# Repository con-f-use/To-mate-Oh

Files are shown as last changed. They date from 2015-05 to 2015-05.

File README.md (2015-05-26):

To-mate-Oh
==========

A [pomodoro](http://pomodorotechnique.com/) timer featuring a <a href="https://en.wikipedia.org/wiki/Capacitive_sensing">capacitve touch button</a>, <a href="https://en.wikipedia.org/wiki/Pulse-width_modulation">PWM</a>-driven LEDs and a <a href="https://en.wikipedia.org/wiki/Piezoelectricity#Actuators">piezo buzzer</a>. Based on the <a href="https://github.com/fakufaku/Pomodoro">Pomodoro project</a> by <a href="http://robinscheibler.org">Robin Scheibler</a> (github: <a href="https://github.com/fakufaku">FakuFaku</a>).

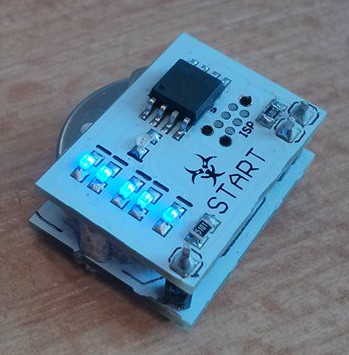
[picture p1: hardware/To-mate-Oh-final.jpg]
Home-cooked To-mate-Oh (not an actual tomato)


*Note: This readme might not always be up to date. Plese consult ./firmware/To-mate-Oh.h and the files in ./docu for more recent information.*

Introduction
------------

I saw the <a href="https://github.com/fakufaku/Pomodoro">POMODORO project</a> by <a href="http://robinscheibler.org">Robin Schreibler</a> and decided to build it. Some may know Robin by the name FakuFaku or from <a href="http://hackaday.com/2014/02/09/hack-all-the-things-in-the-time-you-save-with-this-led-pomodoro-timer/">Hackaday</a>. His' is a very nice layout with beautifully clean code.

__"That can't stand!"__, I thought, so first thing I did was soil the code and complicate the layout. And here is why: I was measuring the power consumption of the original Pomodoro. With a fresh coin cell at 3.3 V, the Pomodoro drained 1.6mA, even when in power down. Your average coin cell has about 200 mAh to give, ignoring the voltage decay. That means after 5 days at most, the battery is gone. This project has since then triggered Robin to fix this bug.

To-mate-Oh schematic. It has reverse polarity protection, four less resistors and replaced the button by a capacitive touch pad

I thought I can do better, and that kind of exploded in my face. Now the board is a quarter of Robin's footprint, has proper reverse polarity protection, drains only about 6 uA (when inactive) and uses less components. Most notably I could do away with four resistors and the switch. The design uses capacitive sensing now and drives the LEDs directly with PWM. The PWM has the added benefit of dimming the LEDs to indicate passed time. You can tweak the duty cycle in code to work with the old hardware (or bridge the unnecessary resistors). On the down side, the code is much, much uglier (but uses only a third of the space on the micro controller). I think it's an improvement, but judge for yourself.

Anyways, many thanks to Robin for making his project open source and being awesome!

Using the Board
---------------

From Robins original documentation (with additions of my own):

1. One click starts a 25 minutes _work_ counter. Five LEDs indicate how many slices of five minutes are left. Every minute the leading led flashes number of times equal to the passed minutes in that slice. It also dims in brightness to indicate the minutes passed. There is a discrete beep when the 25 minute timer expires. The LED then flashes to remind you to go into _rest_ mode.
2. A second click starts a 5 minutes _rest_ counter. The status LED is turned on. There is a discrete beep when it expires. Then the timer turns off.
3. If you wish to turn the timer off during _rest_ mode, click the button a third time.

When you insert a fresh battery, a calibration for the cap sense button is performed. To not touch the upper side of the board during that period. After a successful calibration the To-mate-Oh will circle through its LEDs and beep. If you count the beeps or how often a different LED is lit, it will give you the calibration constant. If the calibration fails, the To-mate-Oh will blink LED2 for five seconds. If this occurs, most likely the sense pad was accidentally connected to a large capacity (e.g. you) or ground.

Making/Ordering the Board
-------------------------

You can order the circuit board at a board house of your choice. e.g. <a href="http://dirtypcbs.com/view.php?share=3243&accesskey=5920ddd4c2010ad6628f47974e820113">Dirty PCBs</a> ($14 to get 20 To-mate-Oh boards). The total price per To-mate-Oh (board + components) should come in at around $3-4. The board is still one sided, but you have to solder the components, break it in two, and sandwich-connect the two halves by soldering them together with solid leads of metal (pin headers work fine). If you live in Germany or Austria, I might be willing to sell you a kit with the board and all components required. Just <a href="mailto:con-f-use@gmx.net?Subject=To-mate-Oh%20Order">contact me</a>.

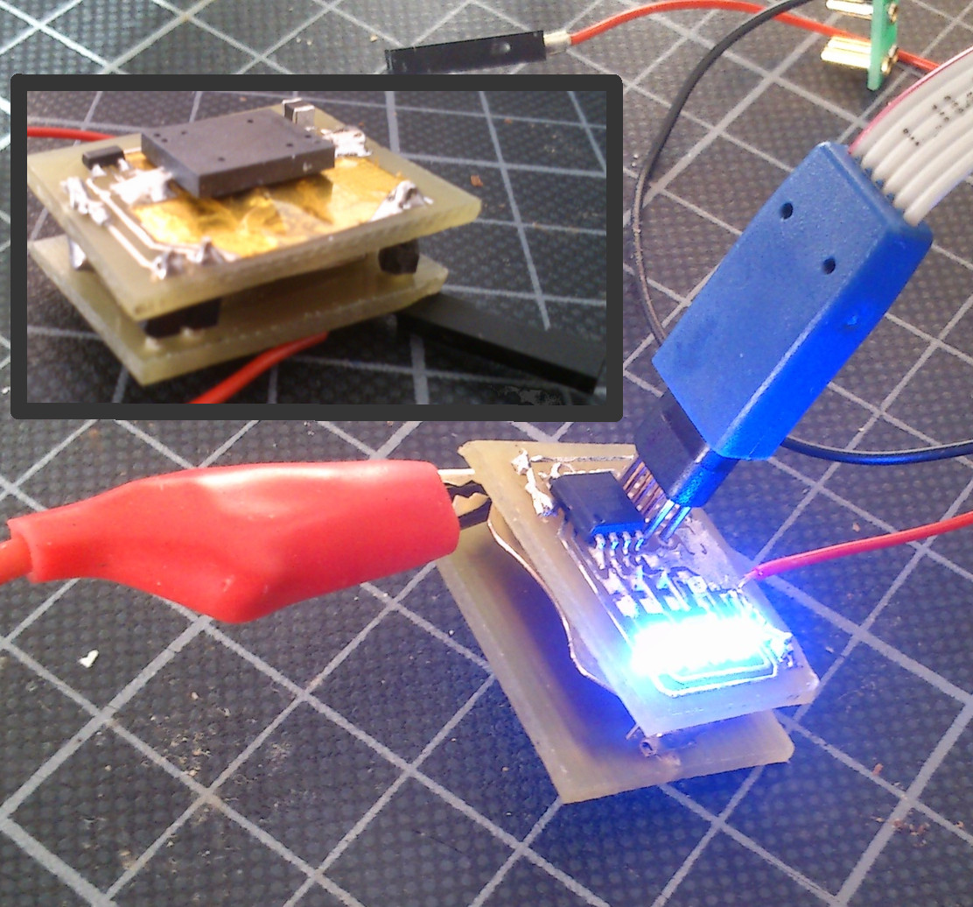
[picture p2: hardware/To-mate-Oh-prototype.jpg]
First prototype being programmed


If you choose to make the board yourself, there are tons of good introductions on <a href="http://hackaday.com/2008/07/28/how-to-etch-a-single-sided-pcb/">how to etch circuit boards</a> at home and <a href="http://store.curiousinventor.com/guides/How_To_Solder"> how to solder</a> (sorry this is pay-for-view now which is very unnerving, try the <a href="https://www.youtube.com/watch?v=b9FC9fAlfQE">EEVBlog tutorial</a>) components to them. With that in mind, the eagle files, pictures and schematics in the ./hardware directory should be all the instructions you need. The coin cell holder is sandwiched between the two halves of the board. You might need to fill the middle trough hole pad under the buzzer with something to make proper contact with the negative contact of the battery on the other side of the board. I listed the components and tools needed below. The components are available e.g. on <a href="https://www.mouser.com/ProjectManager/ProjectDetail.aspx?AccessID=97d69422c2">Mouser</a>. Values and part numbers are only recommendations, use whatever you have. I listed what I used in brackets:

 - Atmel AtTiny25/45/85 microcontroller
 - 5x LED all one color, SMD 0805 (VLMB1300-GS08)*
 - 1x LED any other color, SMD 0805 (VLMS1300-GS08)*
 - 2x 3.3 k Ohm Resistor, SMD 0805[^1]
 - 1x NPN BJT transistor, SOT-23 (BC857)[^2]
 - 1x 220uH Inductor, SMD 1007
 - 1x Buzzer, SMD (Kobitone 254-PB119-ROX)
 - 1x CR2032 coin cell and holder
 - A bit of solid core wire, pin headers or component leads
 - Optional:
    - 1x MOSFET P-Channel, SOT-23 (SI2371ESD)[^3]
    - 1x 1-10 uF Capacitor, SMD 1210[^4]

__Warning: *If you use LEDs other than the Vishay 1300 series, you might get differences in brightness or in very rare cases damage the ATTiny. The LEDs are PWM-dimmed with no current limiting resistor. Not all LEDs have the same efficiency and forward voltage. Current through them may vary. And even at same current, the brightness may vary. The ATTiny must only supply up to 40mA max per output pin and only sink 10mA per input. Additionally all inputs together must not sink more than 60mA (150 mA source per output). A regular CR2032 can provide as muchs as 300mA of current. At the low duty cycles in the program and 3.3V supply voltage from the battery there should be no problem no matter the LEDs. But if you use non-standard LEDs or supply the circuit with more than 3.3V, e.g. when programming, give it a thought or two and consult the <a href="http://www.atmel.com/images/atmel-2586-avr-8-bit-microcontroller-attiny25-attiny45-attiny85_datasheet.pdf">ATTiny's datasheet</a>.__

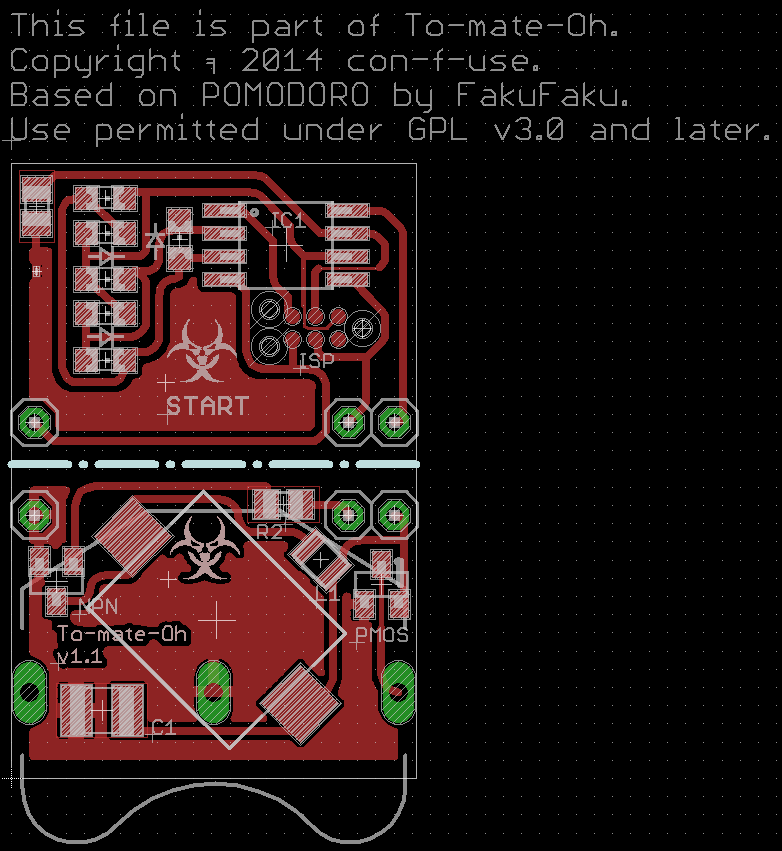
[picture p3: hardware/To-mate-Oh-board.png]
To-mate-Oh Board


Tools for soldering:

- Good soldering ion with small tip for SMD soldering
- Third hand tool
- Wire cutter
- Programmer for the micro controller (e.g. <a href="http://www.geppettoelectronics.com/2014/08/usb-isp-user-guide.html">USB μISP</a>)
- <a href="http://www.tag-connect.com/">Tag connect adapter</a> [^5]

If you are making the board yourself (so you really don't want to order it?):

- Laser printer
- Dremel or similar tool for drilling small holes
- Tool to cut your copper clad board (for thin material -> scissors)
- Cloth iron or laminator (or UV photo resist, developer, transparencies and UV exposure unit)
- Etchant resistant container
- Tab water
- Workspace and clothing that don't mind dirt and discoloration
- __Etchant resistant Gloves__
- __Safety glasses__

__Warning: Etching circuit boards involves corrosive chemicals with the usual dangers (eye damage, chemical burns, damage to the respiratory system, damage to the environment and surroundings, etc.). Know what you're are doing!__

Compiling and flashing the firmware
-----------------------------------

```bash
# Under Ubuntu running these in the ./firmware directory should do:
sudo apt-get install
sudo apt-get install gcc-avr avrdude avr-libc
make flashfuse
```

To flash the firmware to the micro controller run "make flashfuse" after you connected the ISP header on the board to your programmer. The board does not connect the Tag Connect's positive voltage pin to the micro controller. The power pin of your programmer will have to be connected manually to the battery holder's positive contact. This is to avoid exposing an inserted battery to the USB voltage, so **before programming, take the battery out and connect positive voltage yourself.**

The firmware for this project requires avr-gcc and avr-libc (a C-library for the AVR micro controllers). Please read the instructions on how to <a href="http://www.nongnu.org/avr-libc/user-manual/install_tools.html">install the GNU toolchain for avr</a> (avr-gcc, assembler, avr-libc, linker, make, etc.) if above command's did not work for you. Additionally, <a href="http://www.ladyada.net/learn/avr/index.html">Lady Ada's avr tutorial</a> covers the basics of flashing firmware to a micro controller nicely. Running "make flashfuse" in the ./firmware direcotry should be sufficient. You will have to edit the "DEVICE" variable in the Makefile to reflect of the ATTiny25/45/85s you are using. If you are using a programmer other than a <a href="http://www.ladyada.net/make/usbtinyisp/">USBtinyISP</a> variant (btw.: you can build USBtinyISP at home) you need to edit that into the Makefile as well.

If you change the firmware or fuse bits, be aware that the cap sensing and led timing is very sensitive. In the ./firmware/To-mate-Oh.h are a few settings related to LED PWM and timeouts (scroll way down in the .h file until after this documentation).

*Note: There is much room for optimization. For instance, one could get rid of the delays by using a timer for the short led pulses and putting the controller to sleep for the long ones (the watchdog timer can go down to 15 ms). The watchdog timer is not that accurate and temperature stable though. Speaking of accuracy, the delay lengths could be adjusted for more accurate timing.*

Copyright
---------

This file is part of the To-mate-Oh project. Copyright © 2014 con-f-use. Use permitted under GNU General Public License (see LICENSE.txt).

To-mate-Oh is based on the Pomodoro timer by Robin Scheibler (FakuFaku). See <http://robinscheibler.org> and <https://github.com/fakufaku/Pomodoro> for more details on the original project.

To-mate-Oh is a free electronics project: you can redistribute it and/or  modify it under the terms of the GNU General Public License as published by the Free Software Foundation, either version 3 of the License, or (at your option) any later version.

To-mate-Oh is distributed in the hope that it will be useful, but WITHOUT ANY WARRANTY; without even the implied warranty of MERCHANTABILITY or FITNESS FOR A PARTICULAR PURPOSE. See the GNU General Public License for more details.

You should have received a copy of the GNU General Public License along with To-mate-Oh. If not, see <http://www.gnu.org/licenses/>.

The following files comprise To-mate-Oh: ./docu/docu.pdf, ./docu/doxygen.cfg, ./docu/doxygen.sh, ./firmware/Makefile, ./firmware/To-mate-Oh.c, ./firmware/To-mate-Oh.h, ./hardware/To-mate-Oh.brd, ./hardware/To-mate-Oh.sch, ./hardware/To-mate-Oh-board.png, ./hardware/To-mate-Oh-etch.pdf, ./hardware/To-mate-Oh-schematic.pdf, ./hardware/To-mate-Oh-prototype.jpg, ./hardware/To-mate-Oh-final.jpg, ./hardware/To-mate-Oh-kit.jpg, ./hardware/To-mate-Oh-panel.gerber.zip, ./LICENSE.txt, ./README.md

Their use is permitted under the terms of GNU General Public License as well. If you want to use any part under different terms, please feel free to ask the author for his permission.

[^1]: The 3k3 resistor on the base of the NPN shouldn't be lower or it might interfere with programming.
[^2]: The NPN can be pretty generic but should be able to stomach the spikes created by the inductor.
[^3]: The P-MOS should have a threshold voltage well below the battery voltage to work as reverse polarity protection. A low on resistance is nice, too. If you don't use it, short source and drain together. The SI2371ESD is nice because it includes TVS diodes for ESD protection.
[^4]: The 10uF cap is a good thing to enhance battery life by smoothing out peak drains/spikes. It is however not necessary.
[^5]: The tag connect adapter is only needed if you don't want to solder temporary wires for programming. It has a much smaller footprint and some other advantages. Some people have build clones.You could also program the chip off board.

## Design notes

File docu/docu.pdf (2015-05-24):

## To-mate-Oh

1.1

Generated by Doxygen 1.8.6

Mon Jan 12 2015 13:12:34

CONTENTS | 1

## Contents

## 1 To-mate-Oh - A small Pomodoro timer with a capacitive button


Figure 1: Home made To-mate-Oh (not an actual tomato)

Copyright

This file is part of the To-mate-Oh project. Copyright © 2014 con-f-use. Use permitted under GNU General Public License (see LICENSE.txt).
To-mate-Oh is based on the Pomodoro timer by Robin Scheibler (FakuFaku). See http://robinscheibler.-org (http://robinscheibler.org) and https://github.com/fakufaku/Pomodoro for more details on the original project. To-mate-Oh is a free electronics project: you can redistribute it and/or modify it under the terms of the GNU General Public License as published by the Free Software Foundation, either version 3 of the License, or (at
your option) any later version.
To-mate-Oh is distributed in the hope that it will be useful, but WITHOUT ANY WARRANTY; without even the implied warranty of MERCHANTABILITY or FITNESS FOR A PARTICULAR PURPOSE. See the GNU General Public License for more details.
You should have received a copy of the GNU General Public License along with To-mate-Oh. If not, see http://www.gnu.org/licenses/

The following files comprise To-mate-Oh: ./docu/docu.pdf, ./docu/doxygen.cfg, ./docu/doxygen.sh, ./firmware/-
Makefile, | ./firmware/To-mate-Oh.c, | ./firmware/To-mate-Oh.h, | ./hardware/To-mate-Oh.brd, | ./hardware/To-
mate-Oh.sch, | ./hardware/To-mate-Oh-board.png, | ./hardware/To-mate-Oh-etch.pdf, | ./hardware/To-mate-Oh-
schematic.pdf, ./hardware/To-mate-Oh-prototype.jpg, ./hardware/To-mate-Oh-final.jpg, ./hardware/To-mate-Ohkit.jpg, ./LICENSE.txt, ./README,txt

Their use is permitted under the terms of GNU General Public License as well. If you want to use any part under different terms, please feel free to ask the author for his permission.

### 1.1 Introduction

I saw the POMODORO project (https://github.com/fakufaku/Pomodoro) by Robin Schreibler (http://robinscheibler.org) and decided to build it. Some may know Robin by the name FakuFaky. His’ is a very nice layout with beautifully clean code.

Generated on Mon Jan 12 2015 13:12:34 for To-mate-Oh by Doxygen

### 2 CONTENTS

That can’t stand, I thought, so first thing I did was soil the code and complicate the layout. And here is why: I was measuring the power consumption of the original POMODORO. With a fresh coin cell at 3.3 V, the POMODORO drained 1.6mA, even when in power down. Your average coin cell has about 200 mAh to give, ignoring the voltage decay. That means after 5 days at most, the battery is gone.

11/5/14 9:57 PM /home/confus/eagle/To-mate-Oh/hardware/To-mate-Oh.sch (Sheet: 1/1)

VCC

8 | PB1(MISO) | 6 PB5(NRES) | 1 GND
4 | PB0(MOSI) | 5 PB2(SCK/ADC1) | 7 PB3(ADC3) | 2 PB4(ADC2) | 3

MISO

1 | +V
2 | | SCK
3 | MOSI 4 | RST
5 | | GND
6
1 | 1
1 | 1
1 | 1

TCH

P$1

A

B

C

D

1 | 2 | 3 | 4

A

B

C

D

1 | 2 | 3 | 4

Figure 2: New To-mate-Oh schematic. It has reverse polarity protection, four less resistors and replaced the button by a capacitive touch pad.

I thought I can do better, and that kind of exploded in my face. Now the board is a quarter of Robin’s footprint, has proper reverse polarity protection, drains only 7 uA when inactive and uses less components. Most notably I could do away with four resistors and the switch. The design uses capacitive sensing now. The code still works with the old hardware though. On the down side, the code is much uglier (but uses only a third of the space on the micro controller). I think it’s an improvement, but judge for yourself.

Anyways, many thanks to Robin for making his project open source and being awesome!

### 1.2 Making the Board

You can order the circuit board at a board house of your choice. e.g. Dirty PCBs. (http://dirtypcbs.com/view.php?share=3243&accesskey=5920ddd4c2010ad6628f47974e820113) The board is still one sided, but you have to solder the components, break it in two, and sandwich-connect the two halves by soldering them together with solid leads of metal (pin headers work fine).

1.2 Making the Board | 3


Figure 3: First prototype being programmed

If you choose to make the board yourself, there are tons of good introductions on how to etch circuit boards (http://hackaday.com/2008/07/28/how-to-etch-a-single-sided-pcb/) at home and how to solder (http://store.curiousinventor.com/guides/How_To_Solder) components to them. With that in mind, the eagle files, pictures and schematics in the ./hardware directory should be all you need, except for the components of course. I listed the components and tools needed below. The components are available e.g. on Mouser. (https://mouser.com) Exact values and part numbers are only recommendations. I listed what I used in brackets:

- Atmel AtTiny25/45/85 microcontroller
- 5x LED all one color, SMD 0805 (VLMB1300-GS08)∗
- 1x LED any other color, SMD 0805 (VLMS1300-GS08)∗
- 2x 3.3 k Ohm Resistor, SMD 0805 1
- 1x NPN BJT transistor, SOT-23 (BC857) 2
- 1x 220uH Inductor, SMD 1007
- 1x Buzzer, SMD (Kobitone 254-PB119-ROX)
- 1x CR2032 coin cell and holder
- Optional:
1x MOSFET P-Channel, SOT-23 (SI2371) 3 ,
1x 10 uF Capacitor, SMD 1210 4

Warning

If you use LEDs other than the Vishay 1300 series, you might get differences in brightness and even damage your micro controller. The LEDs are PWM-dimmed with no current limiting resistor. Not all LEDs have the same efficiency and forward voltage, meaning current through them may vary. And even at same current, the brightness may vary. The ATTiny must only supply up to 40mA max per output pin and only sink 10mA per input. Additionally all inputs together must not sink more than

1The 3k3 resistor on the base of the NPN shouldn’t be lower or it might interfere with programming.
2The NPN can be pretty generic but should be able to stomach the spikes created by the inductor.
3The P-MOS should have a threshold voltage well below the battery voltage to work as reverse polarity protection. A low on resistance is nice, too. If you don’t use it, short source and drain together.
4The 10uF cap is a good thing to enhance battery life by smoothing out peak drains/spikes. It is however not necessary.

### 4 CONTENTS

60mA (150 mA source per output). At the low duty cycles in the program and 3.3V supply voltage from the battery there should be no problem no matter the LEDs. But if you use non-standard LEDs or supply the circuit with more than 3.3V, e.g. when programming, give it a thought or two and consult the ATTiny’s datasheet (http://www.atmel.com/images/atmel-2586-avr-8-bit-microcontroller-attiny25-attiny45-attiny85_datasheet.pdf) .

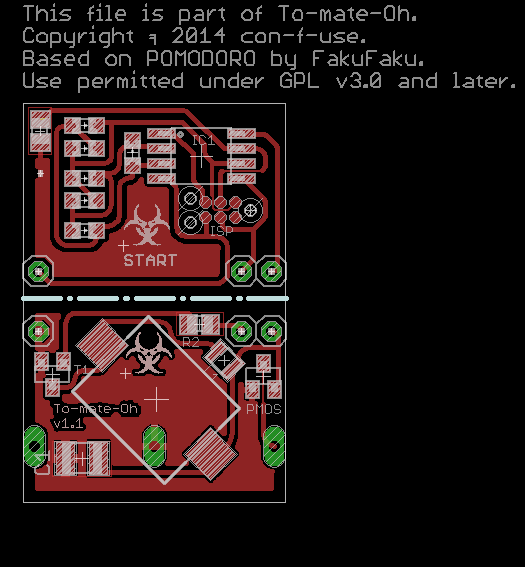
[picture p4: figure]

Figure 4: To-mate-Oh Board

Tools for soldering:

- Good soldering ion with small tip for SMD soldering
- Third hand tool
- Clothing ion
- Programmer for the micro controller
- Tag connect adapter (http://www.tag-connect.com/) 5

If you are making the board yourself (if you really don’t want to order it):

- Laser printer
- Dremel or similar tool for drilling small holes
- Tool to cut your copper clad board (for thin material -> scissors)
- Cloth iron or laminator
- Acid resistant Gloves
- Acid resistant container to hold your etching solution
- Safety glasses

Warning

Etching circuit boards involves corrosive chemicals with the usual dangers (eye damage, chemical burns, damage to the respiratory system, etc.).

5The tag connect adapter is only needed if you don’t want to solder temporary wires for programming. It has a much smaller footprint and some other advantages. Some people have build clones.You could also program the chip off board.

1.3 Compiling and flashing the firmware | 5

### 1.3 Compiling and flashing the firmware

The firmware for this project requires avr-gcc and avr-libc (a C-library for the AVR controller). Please read the instructions at http://www.nongnu.org/avr-libc/user-manual/install_tools.html for how to install the GNU toolchain (avr-gcc, assembler, linker etc.) and avr-libc.

Lady Ada’s avr tutorial (http://www.ladyada.net/learn/avr/index.html) covers the basics of flashing firmware to a microcontroller nicely.

However, running "make program" in the firmware direcotry should be sufficient. Maybe you will have to edit the Makefile especially if you are using a programmer other than USBtinyISP (http://www.ladyada.net/make/usbtinyisp/) (btw.: you can build USBtinyISP at home).

To flash the firmware to the microcontroller run "make flashfuse" after you connected the ISP header on the board to your programmer. The board does not connect the Tag Connect’s plus pin to the micro controller. The power pin of your programmer will have to be connected manually to the battery holder’s positive contact. This is to avoid exposing an inserted battery to the USB voltage, so before programming, take the battery out.

If you change the firmware or fuse bits, be aware that the cap sensing and led timing is very sensitive. In the ./firmware/To-mate-Oh.h are a few settings related to LED PWM and timeouts (scroll way down in the .h file until after this documentation).

Note

There is much room for optimization. For instance, one could get rid of the delays by using a timer for the short led pulses and putting the controller to sleep for the long ones (the watchdog timer can go down to 15 ms). The watchdog timer is not that accurate and temperature stable though. Speaking of accuracy, the delay lengths could be adjusted for more accurate timing.

### 1.4 Using the Board

From Robins original documentation:

1. One click starts a 25 minutes work counter. Five yellow LED indicates how many slices of five minutes are left. There is a discrete beep when the timer expires. The LED then flashes to remind you to go into rest mode.
2. A second click starts a 5 minutes rest counter. A red LED is turned on. There is a discrete beep when it expires. Then the timer turns off.
3. If you wish to turn the timer off during rest mode, click the button a third time.

When you insert a fresh battery, a calibration for the cap sense button is performed. After a successful calibration the To-mate-Oh will circle through its LEDs and beep. If you count the beeps or how often a different LED is lit, it will give you the calibration constant. If the calibration fails, the To-mate-Oh will blink LED2 for five seconds. Most likely the sense pad is connected to a large capacity or ground then.

## 2 File Index

### 2.1 File List

Here is a list of all files with brief descriptions:

/home/confus/misc/prog/eagle/To-mate-Oh/firmware/To-mate-Oh.c
Contains the firmware to flash the microcontroler on the To-mate-Oh | ??

/home/confus/misc/prog/eagle/To-mate-Oh/firmware/To-mate-Oh.h
Contains the prototypes, constants and global definitions as well as the documentation of To-
mate-Oh, a little timer device for use with the pomodoro technique (http://pomodorotechnique.com) | ??

### 6 CONTENTS

## 3 File Documentation

3.1 /home/confus/misc/prog/eagle/To-mate-Oh/firmware/To-mate-Oh.c File Reference

Contains the firmware to flash the microcontroler on the To-mate-Oh.

#include <avr/io.h>

#include <util/delay.h>

#include <avr/power.h>

#include <avr/wdt.h>

#include <avr/sleep.h>

#include <avr/interrupt.h> #include "To-mate-Oh.h"

Functions

- int main (void)
- void handle_button_press ()

Invokes the respective actions, when the button was pressed.
- EMPTY_INTERRUPT (WDT_vect)
- void Sleep_now (uint8_t periods, uint8_t timeout)

Put microcontroller into sleep mode to conserve power.
- void Set_leds (int led)

Access individual LEDs through charlieplexing.
- void Shine_led (int led, uint32_t duration)

Poor PWM for dimming an led for a duration given in multiples of 10ms.
- void Start_buzz ()

Start the piezo buzzer.
- void Stop_buzz ()

Stop the piezo buzzer.
- void Play_sound ()

Plays the indicator melody.
- unsigned Get_time ()

Measure the time to charge the button.
- unsigned Get_cal ()

Calibrate charge time of the button.

### 3.1.1 Detailed Description

Contains the firmware to flash the microcontroler on the To-mate-Oh. The program is for a little battery powered timer device that can be used with the pomodoro technique. (http://pomodorotechnique.com)

Date

25 Oct 2014

Author

con-f-use

Copyright

This file is part of To-mate-Oh. Copyright © 2014 con-f-use. Use permitted under GNU General Pub-
lic License v3.0. | It is based on the Pomodoro timer by Robin Scheibler (FakuFaku). | See: http-
://robinscheibler.org and https://github.com/fakufaku/Pomodoro for more details on the original project.

3.2 /home/confus/misc/prog/eagle/To-mate-Oh/firmware/To-mate-Oh.h File Reference | 7

### 3.1.2 Function Documentation

### 3.1.2.1 EMPTY_INTERRUPT ( WDT_vect )

### 3.1.2.2 unsigned Get_cal ( )

Calibrate charge time of the button.

This time is later used to detect a button press.

### 3.1.2.3 unsigned Get_time ( )

Measure the time to charge the button.

Takes the sum of several charge cycles to be more sensitive.

Returns

Time it took to charge the button

### 3.1.2.4 void handle_button_press ( )

Invokes the respective actions, when the button was pressed.

### 3.1.2.5 int main ( void )

### 3.1.2.6 void Play_sound ( )

Plays the indicator melody.

### 3.1.2.7 void Set_leds ( int led )

Access individual LEDs through charlieplexing.

### 3.1.2.8 void Shine_led ( int led, uint32_t duration )

Poor PWM for dimming an led for a duration given in multiples of 10ms.

### 3.1.2.9 void Sleep_now ( uint8_t , uint8_t )

Put microcontroller into sleep mode to conserve power.

Although the ATTiny25 supports it on paper, using timeouts over two seconds leads to strange behavior in test cases. So use "WDTO_2S" as absolute maximum timeout!

### 3.1.2.10 void Start_buzz ( )

Start the piezo buzzer.

### 3.1.2.11 void Stop_buzz ( )

Stop the piezo buzzer.

3.2 /home/confus/misc/prog/eagle/To-mate-Oh/firmware/To-mate-Oh.h File Reference

Contains the prototypes, constants and global definitions as well as the documentation of To-mate-Oh, a little timer device for use with the pomodoro technique. (http://pomodorotechnique.com)

Macros

- #define BTN_THRESHOLD 2

### 8 CONTENTS

Threshold for the button to detect user input.
- #define ON_TIME 5

LED on time per PWN cycle in units of 100us.
- #define DUTY 5

Duty cycle of the LED.
- #define WORK 1

Timer is counting down a Pomodro (25min chunk)
- #define WAIT 3

Waiting for user to start rest period.
- #define REST 4

5 min rest
- #define T_ON ((uint32_t)(ON_TIME)∗100)
- #define T_CYC (T_ON∗100/(uint32_t)(DUTY))
- #define T_OFF (T_CYC-T_ON)

Functions

- void Config_wdt (uint8_t)

Intializes the watchdog timer and sets the microcontroller’s pins properly.
- void Sleep_now (uint8_t, uint8_t)

Put microcontroller into sleep mode to conserve power.
- void Set_leds (int led)

Access individual LEDs through charlieplexing.
- void Shine_led (int led, uint32_t duration)

Poor PWM for dimming an led for a duration given in multiples of 10ms.
- void Start_buzz ()

Start the piezo buzzer.
- void Stop_buzz ()

Stop the piezo buzzer.
- void Play_sound ()

Plays the indicator melody.
- unsigned Get_time ()

Measure the time to charge the button.
- unsigned Get_cal ()

Calibrate charge time of the button.
- void handle_button_press ()

Invokes the respective actions, when the button was pressed.

Variables

- unsigned cal

Storage for the calibration values of the button.
- unsigned char state

Current state the timer is in.

3.2 /home/confus/misc/prog/eagle/To-mate-Oh/firmware/To-mate-Oh.h File Reference | 9

### 3.2.1 Detailed Description

Contains the prototypes, constants and global definitions as well as the documentation of To-mate-Oh, a little timer device for use with the pomodoro technique. (http://pomodorotechnique.com) User input is sensed via a time integration to sense capacity in the "button". An average charging time is computed before hand. This time in turn then serves as a calibration value to detect the button press.

The charging time changes with the capacity of the button, which in turn is changed when a human comes near the button. A daramtic increase in charging time means an increase in capacity and thus something touching the button.

Date

25 Oct 2014

Author

con-f-use

Copyright

This file is part of To-mate-Oh. Copyright © 2014 con-f-use. Use permitted under GNU General Pub-
lic License v3.0. | It is based on the Pomodoro timer by Robin Scheibler (FakuFaku). | See: http-
://robinscheibler.org and https://github.com/fakufaku/Pomodoro for more details on the original project.

### 3.2.2 Macro Definition Documentation

3.2.2.1 #define BTN_THRESHOLD 2

Threshold for the button to detect user input.

3.2.2.2 #define DUTY 5

Duty cycle of the LED.

3.2.2.3 #define ON_TIME 5

LED on time per PWN cycle in units of 100us.

3.2.2.4 #define REST 4

5 min rest

3.2.2.5 #define T_CYC (T_ON∗100/(uint32_t)(DUTY))

3.2.2.6 #define T_OFF (T_CYC-T_ON)

3.2.2.7 #define T_ON ((uint32_t)(ON_TIME)∗100)

3.2.2.8 #define WAIT 3

Waiting for user to start rest period.

3.2.2.9 #define WORK 1

Timer is counting down a Pomodro (25min chunk)

### 3.2.3 Function Documentation

### 10 CONTENTS

### 3.2.3.1 void Config_wdt ( uint8_t )

Intializes the watchdog timer and sets the microcontroller’s pins properly.

### 3.2.3.2 unsigned Get_cal ( )

Calibrate charge time of the button.

This time is later used to detect a button press.

### 3.2.3.3 unsigned Get_time ( )

Measure the time to charge the button.

Takes the sum of several charge cycles to be more sensitive.

Returns

Time it took to charge the button

### 3.2.3.4 void handle_button_press ( )

Invokes the respective actions, when the button was pressed.

### 3.2.3.5 void Play_sound ( )

Plays the indicator melody.

### 3.2.3.6 void Set_leds ( int led )

Access individual LEDs through charlieplexing.

### 3.2.3.7 void Shine_led ( int led, uint32_t duration )

Poor PWM for dimming an led for a duration given in multiples of 10ms.

### 3.2.3.8 void Sleep_now ( uint8_t , uint8_t )

Put microcontroller into sleep mode to conserve power.

Although the ATTiny25 supports it on paper, using timeouts over two seconds leads to strange behavior in test cases. So use "WDTO_2S" as absolute maximum timeout!

### 3.2.3.9 void Start_buzz ( )

Start the piezo buzzer.

### 3.2.3.10 void Stop_buzz ( )

Stop the piezo buzzer.

### 3.2.4 Variable Documentation

### 3.2.4.1 unsigned cal

Storage for the calibration values of the button.

### 3.2.4.2 unsigned char state

Current state the timer is in.

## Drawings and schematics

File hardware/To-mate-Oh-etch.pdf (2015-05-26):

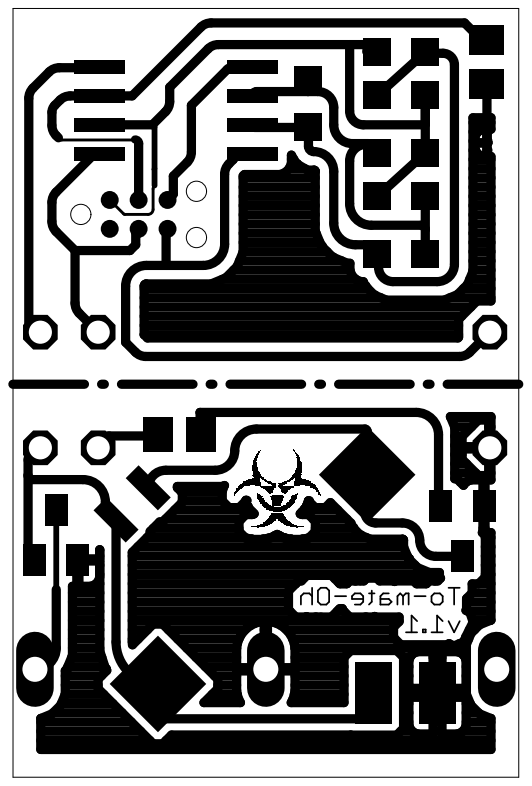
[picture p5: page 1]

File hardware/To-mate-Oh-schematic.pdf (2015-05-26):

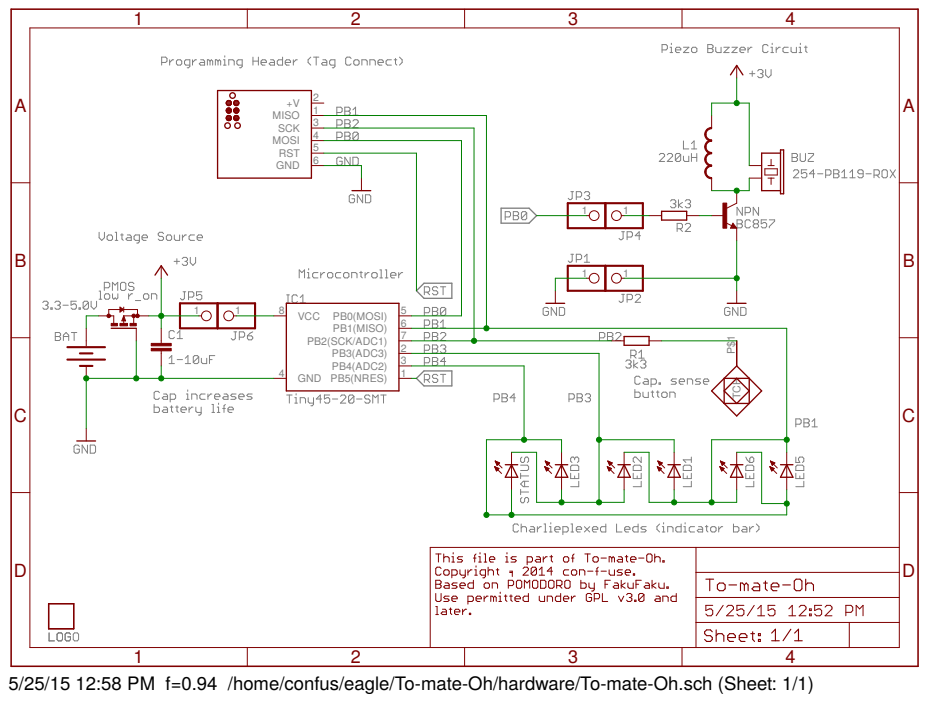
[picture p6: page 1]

5/25/15 12:58 PM f=0.94 /home/confus/eagle/To-mate-Oh/hardware/To-mate-Oh.sch (Sheet: 1/1)

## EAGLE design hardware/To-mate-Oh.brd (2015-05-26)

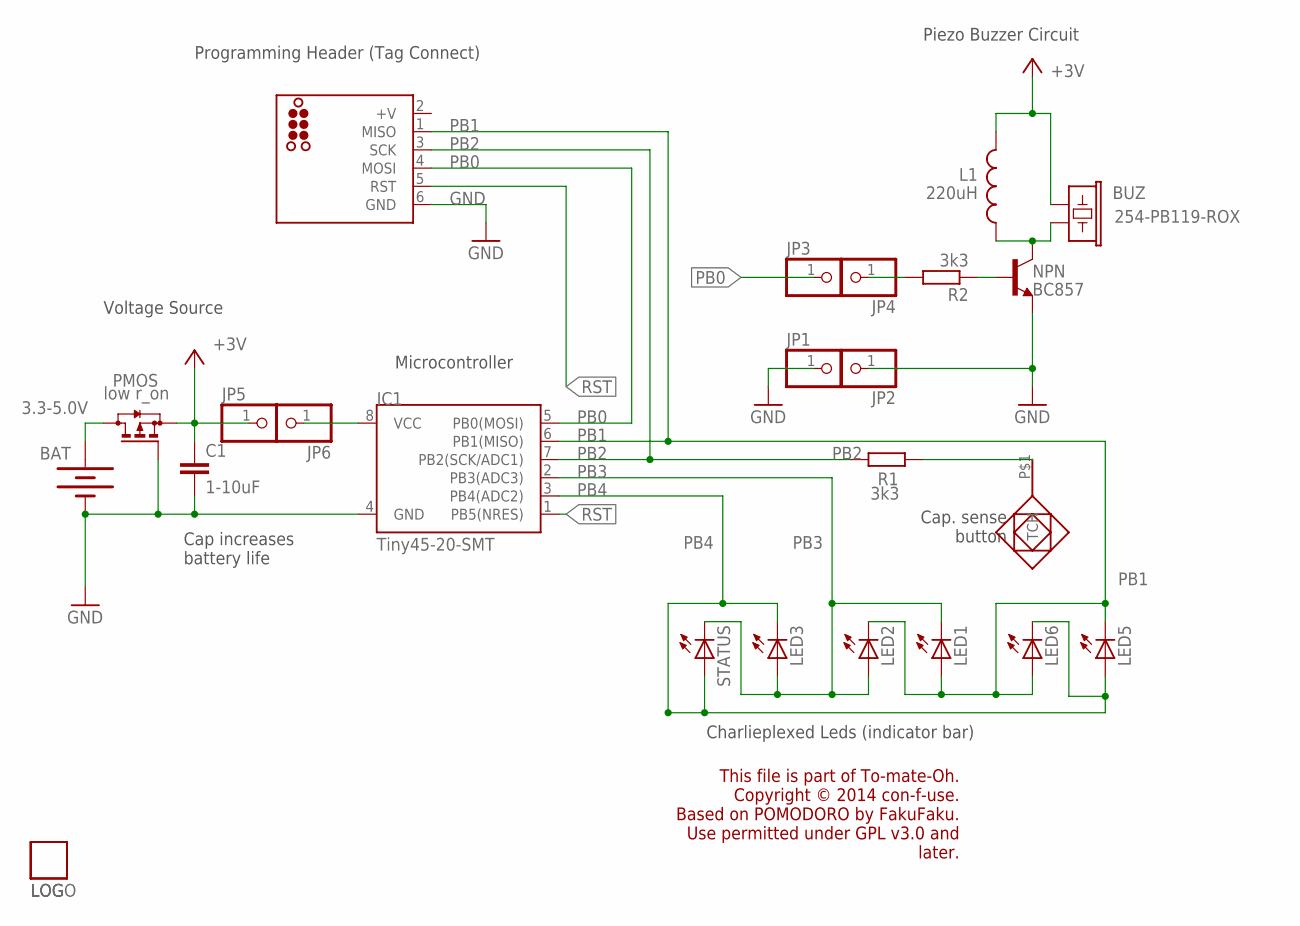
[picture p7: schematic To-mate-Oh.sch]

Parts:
BAT: 3.3-5.0V; BATTERY_20MM_PTH_COMPACT
BUZ: 254-PB119-ROX; BUZZER-CMT1102
C1: 1-10uF; C1210
CAP_SENSE: PAD; EMPTY
IC1: Tiny45-20-SMT; SO08-EIAJ
ISP: ATMEL-ISPATMEL_ISP_TC2030; TC2030-MCP-NL
JP1: JGND1; 1X01
JP2: JGND2; 1X01
JP3: JPB1; 1X01
JP4: JPB2; 1X01
JP5: JVCC1; 1X01
JP6: JVCC2; 1X01
L1: 220uH; 1007
LED1, LED2, LED3, LED5, LED6: Blue; CHIPLED_0805
LOG: UNETHILOGO; UNETHILOGO_TINY_SILK
LOGO: UNETHILOGOUNETHILOGO_TINY; UNETHILOGO_TINY
NPN: BC857; SOT23-BEC
PMOS: low r_on; SOT23
R1, R2: 3k3; R0805
STATUS: Red; CHIPLED_0805

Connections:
+V: ISP.2 (+V)
BAT+: BAT.1 (+), BAT.1@2 (+), PMOS.3 (D)
BTN: CAP_SENSE.P$1, R1.2
GND: BAT.2 (-), C1.2, IC1.4 (GND), ISP.6 (GND), JP1.1, JP2.1, NPN.E, PMOS.1 (G)
unnamed: JP4.1, R2.2
unnamed: NPN.B, R2.1
unnamed: IC1.8 (VCC), JP6.1
unnamed: BUZ.2, L1.1, NPN.C
PB0: IC1.5 (PB0(MOSI)), ISP.4 (MOSI), JP3.1
PB1: IC1.6 (PB1(MISO)), ISP.1 (MISO), LED1.A, LED2.C, LED5.C, LED6.A
PB2: IC1.7 (PB2(SCK/ADC1)), ISP.3 (SCK), R1.1
PB3: IC1.2 (PB3(ADC3)), LED1.C, LED2.A, LED3.A, STATUS.C
PB4: IC1.3 (PB4(ADC2)), LED3.C, LED5.A, LED6.C, STATUS.A
RST: IC1.1 (PB5(NRES)), ISP.5 (RST)
VCC: BUZ.1, C1.1, JP5.1, L1.2, PMOS.2 (S)

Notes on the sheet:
Programming Header (Tag Connect)
Piezo Buzzer Circuit
Charlieplexed Leds (indicator bar)
Microcontroller
Voltage Source
Cap. sense button
This file is part of To-mate-Oh. Copyright © 2014 con-f-use. Based on POMODORO by FakuFaku. Use permitted under GPL v3.0 and later.
Cap increases battery life

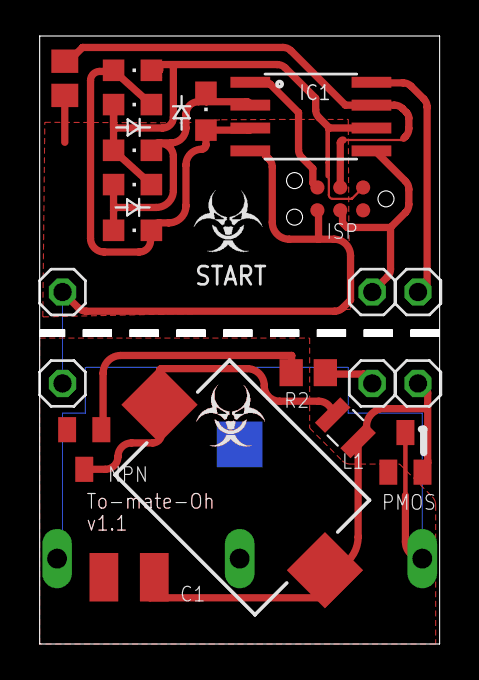
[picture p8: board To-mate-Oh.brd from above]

Board: 2 copper layers, 22.2 x 33.8 mm, 25 parts (1 on the bottom side), 14 nets.

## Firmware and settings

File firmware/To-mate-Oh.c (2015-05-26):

/* Indent: space, Tabsize: 4, Encoding: UTF-8, Language: C/Eng, Breaks: linux */
/**
 * \file To-mate-Oh.c
 *
 * Contains the firmware to flash the microcontroler on the To-mate-Oh.
 *
 * The program is for a little battery powered timer device that can be used
 * with the <a href="http://pomodorotechnique.com">pomodoro technique</a>.
 *
 * \date 25 Oct 2014
 * \author <a href="mailto:con-f-use@gmx.net">con-f-use</a>
 * \copyright
 * This file is part of To-mate-Oh. Copyright © 2014 con-f-use. Use permitted
 * under GNU General Public License v3.0. It is based on the Pomodoro timer by
 * Robin Scheibler (FakuFaku). See: http://robinscheibler.org and
 * https://github.com/fakufaku/Pomodoro for more details on the original
 * project.
 */

// INCLUDES
#include <avr/io.h>         // standard input/output for handy macros
#include <util/delay.h>     // for delay functions
#include <avr/power.h>      // handy power down commands
#include <avr/wdt.h>        // easy control of the watchdog (wakes the device)
#include <avr/sleep.h>      // sleep mode for lower power consumption
#include <avr/interrupt.h>  // for sei()
#include "To-mate-Oh.h"

int main(void) {
    unsigned i;

    // SETUP
    state = WORK;         // When not idling go to work
    cal = Get_cal();      // Calibrate the touch button

    // INDICATE READINESS (and led/buzzer function & calibration value)
    for(i=0; i<cal; ++i) {
      Shine_led(i%6, 10);   _delay_ms(10);
      if( i>5 && Get_time()>cal ) break;
    }

    // MAIN LOOP
    while( 1 ) {
      if( Get_time()>cal ) Handle_button_press();
      Sleep_now(1, WDTO_500MS);
    }

    return 0;
}

//###################################################################### Timing

void Handle_button_press() {
    int i, j;
    unsigned char k;
    uint32_t t_led;
    unsigned char tmp;
    unsigned char leds;
    uint16_t bright=T_ON;
    uint16_t on_iter;

    if(state==WORK) {
        tmp = 0; leds = 5; // Initially all five LEDs on
        // Cycle through the leds
        for( i=0; i<25; ++i) { // 25 iterations, each one minute
          j = i%5;
          if( j==0 ) {
            leds--;   // turn off one led every 5 minutes
            bright = T_ON-10;
          }
          bright>>=1; // reduce brightness of leading led every minute

          for( t_led=0; t_led<(uint32_t)6e7/T_CYC; ++t_led) {

            // Blink led to indicate time in the fifth of a pomodoro
            if( j>0 && t_led%((uint32_t)5e5/T_CYC)==0 ) {
              if(tmp == 0) { --leds; tmp=1; }
              else { ++leds; --j; tmp=0; }
            }

            // PWM the leds
            for( k=0; k<6; ++k ) {
              Set_leds(leds-k);
              if( k==0 ) {
                for(on_iter=0; on_iter<bright; ++on_iter)
                  _delay_us(1);
                Set_leds(-1);
                for(on_iter=0; on_iter<T_ON-bright-10; ++on_iter) _delay_us(1);
              } else {
                _delay_us(T_ON);
                Set_leds(-1);
              }
              _delay_us( (T_OFF-T_ON*5)/6-150 );
            }

            // Check for user abort
            if( t_led>(uint32_t)1e6/T_CYC && Get_time()>cal ) {
              state = REST; i=25; break;
            }
          }
        }
        if( state != REST ) { state = WAIT; Play_sound(); }
    }

    if(state==WAIT) {
        // Blink red led until button is pressed or go to idle if timed out
        for(t_led=0; t_led<300; t_led++) {
          Shine_led(5, 49);  Sleep_now(1, WDTO_500MS);
          if( t_led>5 && Get_time()>cal ) { state = REST; break; }
        }
        if(state != REST) { state=WORK; return; }
    }

    if(state==REST) {
        for(t_led=0; t_led<300; ++t_led) {
          Shine_led(5, 100);
          if( t_led%60==59 ) Sleep_now(1, WDTO_500MS);
          if( Get_time()>cal ) { state=WORK; return; };
        }
        state = WORK;
    }

    Play_sound();
}

//=============================================================================
// HELPERS
//=============================================================================

//###################################################################Sleep mode

EMPTY_INTERRUPT(WDT_vect);

void Sleep_now(uint8_t periods, uint8_t timeout) {
  cli();
  wdt_reset();
  wdt_disable();
  // correct WDP3 location
  timeout |= ((timeout&(1<<3))<<2);
  timeout &=~(1<<3);
  MCUSR = 0x00;
  WDTCR = (1<<WDE) | (1<<WDCE); // enable watchdog
  WDTCR = (1<<WDIE) | timeout;  // watchdog interrupt instead of reset
  //+reset, timeout can be 15,30,60,120,250,500ms or 1,2,4,8s
  sei();
  for( ; periods>0; --periods) {
    set_sleep_mode(SLEEP_MODE_PWR_DOWN);  // set type of sleepmode
    power_all_disable();                  // disable unneeded loads
    wdt_reset();                          // timer should start at zero
    sleep_enable();                       // approach sleep mode
    sleep_mode();                         // enter sleep mode (confirm)
    sleep_disable();                      // entrance point when woken up
    wdt_disable();
    power_all_enable();                   // re-enable the loads
  }
}

//###################################################################Indicators

void Set_leds(int led) { // Same as Robin's version except for white spaces.
  switch (led) {
    case 2:         // LED1
      DDRB |= (1 << DDB3);  DDRB |= (1 << DDB1);  DDRB &= ~(1 << DDB4);
      PORTB &= ~(1 << 3);   PORTB &= ~(1 << 4);   PORTB |= (1 << 1);
    break; case 3:  // LED2
      DDRB |= (1 << DDB3);  DDRB |= (1 << DDB1);  DDRB &= ~(1 << DDB4);
      PORTB &= ~(1 << 1);   PORTB &= ~(1 << 4);   PORTB |= (1 << 3);
    break; case 4:  // LED3
      DDRB |= (1 << DDB3);  DDRB |= (1 << DDB4);  DDRB &= ~(1 << DDB1);
      PORTB &= ~(1 << 1);   PORTB &= ~(1 << 4);   PORTB |= (1 << 3);
    break; case 5:  // LED4 (button side)
      DDRB |= (1 << DDB3);  DDRB |= (1 << DDB4);  DDRB &= ~(1 << DDB1);
      PORTB &= ~(1 << 1);   PORTB &= ~(1 << 3);   PORTB |= (1 << 4);
    break; case 0:  // LED5 (other color)
      DDRB |= (1 << DDB1);  DDRB |= (1 << DDB4);  DDRB &= ~(1 << DDB3);
      PORTB &= ~(1 << 3);   PORTB &= ~(1 << 1);   PORTB |= (1 << 4);
    break; case 1:  // LED6
      DDRB |= (1 << DDB1);  DDRB |= (1 << DDB4);  DDRB &= ~(1 << DDB3);
      PORTB &= ~(1 << 3);   PORTB &= ~(1 << 4);   PORTB |= (1 << 1);
    break; default: // turn all LEDs off
      DDRB &= ~(1 << DDB1) & ~(1 << DDB3) & ~(1 << DDB4);
      PORTB &= ~(1 << 1) & ~(1 << 3) & ~(1 << 4);;
    break;
  }
}

void Shine_led(int led, uint32_t duration) {
  duration = (duration*10000)/T_CYC;
  for( ; duration>0; --duration ) {
        Set_leds(led);    _delay_us(T_ON);
        Set_leds( -1);    _delay_us(T_OFF);
  }
}

void Start_buzz() {
  DDRB |= (1 << DDB0); // set PB0 output

  // Fast PWM, OC0A, non-inverting, divide clock by 8 (~4kHz @ clk 8MHz)
  TCCR0A = (1 << COM0A1) | (1 << WGM01) | (1 << WGM00);
  TCCR0B = (1 << CS01);
  OCR0A = 128;  // half duty cycle
}

void Stop_buzz() {
  TCCR0A = 0x0;         // stop timer
  DDRB &= ~(1 << DDB0); // set PB0 as input
}

void Play_sound() {
    unsigned i;
    unsigned char j;
    unsigned char duration[] = {2, 1, 1};

    for(i=0; i<11; ++i) {
        Start_buzz();
        for(j=0; j<duration[i%3];++j) Shine_led(0, 35);
        Stop_buzz();
        _delay_ms(50);
    }
}

//################################################################# Cap sensing

unsigned Get_time() {
    unsigned i = 0;
    const uint8_t mask = (1 << PB2);

    // MEASURE THE TIME FOR THE BUTTON TO CHARGE
    PORTB &= ~mask;         // pull-up off
    DDRB  |=  mask;         // discharge
    while( PINB & mask );   // wait till discharge complete
    _delay_us(10);          // wait some more for good measure
    DDRB  &= ~mask;         // set pin to input
    TCCR1 = (1 << CS10);    // enable timer at CPU frequency

    PORTB |=  mask;         // internal pull-up on
    TCNT1 = 0;              // reset timer
    while((PINB & mask)<1); // wait for pin to charge
    i=TCNT1;                // get time
    TCCR1 = 0;              // disable timer
    if( TIFR&(1<<TOV1) ) {  // If there was a timer overflow
      i=255;
      TIFR |= (1<<TOV1);    // Clear timeout flag
    }

    PORTB &= ~mask;         // pull-up off
    return i;
}

unsigned Get_cal() {
    int i;
    uint16_t stime = 0;

    _delay_ms(10);  // wait till controller has settled

    // Measure a couple discharge times, then calculate the average
    for(i=1<<3; i>0; --i) stime += Get_time();
    stime >>= 3;    // division to get the mean
    // Indicate Cal Error
    if( stime >= 255 || stime < 2 ) { // constant too large or small
      for(i=0; i<5; ++i) { Shine_led(3, 50); Sleep_now(1, WDTO_500MS); }
      return stime;
    }
    return stime + BTN_THRESHOLD;
}

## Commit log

2015-05-24 To-mate-Oh initial commit
    [To-mate-Oh.brd, To-mate-Oh.sch, doxygen.cfg]
2015-05-26 Added readme
    Update README.md
    Update README.md
    Update README.md
    Update README.md
    Update README.md
    Minor cosmetics
    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
    [To-mate-Oh.brd, To-mate-Oh.sch]

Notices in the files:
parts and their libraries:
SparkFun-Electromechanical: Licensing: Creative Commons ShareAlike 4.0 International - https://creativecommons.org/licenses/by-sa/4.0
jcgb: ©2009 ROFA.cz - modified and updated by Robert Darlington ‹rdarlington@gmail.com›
